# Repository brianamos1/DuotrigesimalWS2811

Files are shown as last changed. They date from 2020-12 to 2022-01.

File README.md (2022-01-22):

# DuotrigesimalWS2811
A board for driving 32 strings of pixels from a Teensy 4.1. Similar to the OctoWS2811, but with 32 outputs. 

This board interfaces with a Teensy 4.1, and is designed to use the OctoWS2811 library to drive up to 32 strings of LEDS. 

Version 0.2 is designed to use the Amphenol RJHSE508004-ND, which is a four port RJ45 jack.  Version 0.2a uses the Adam Tech MTJG-4-88GX1-FSB, which is a less expensive and more readily available alternative.

The 2x3 pin that connects the board to the Teensy 4.1's ethernet pins is available on digikey and mouser, however is easier to source from PJRC when purchasing the Teensy 4.1.  If you want the teensy to be removable, PJRC is the recommended source for that connector.  If you're going to solder the T4.1 to this board, then it doesn't matter the source for the pins.  ‎

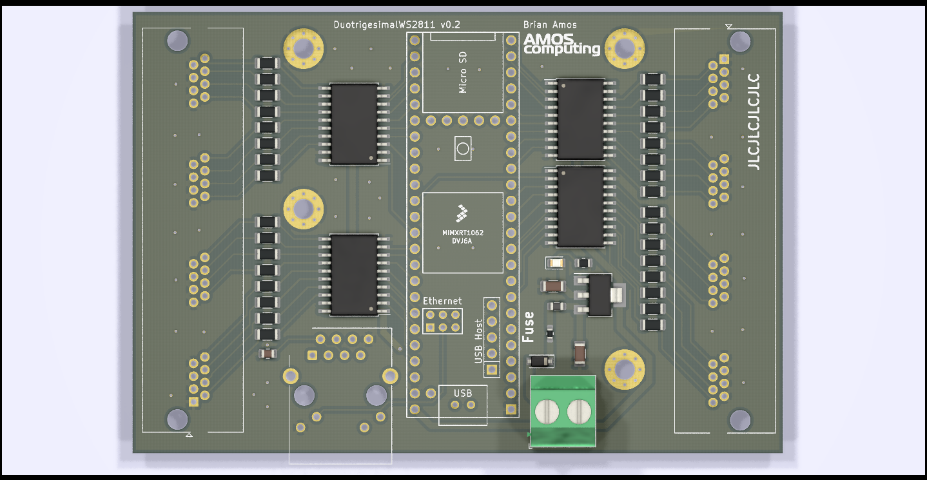
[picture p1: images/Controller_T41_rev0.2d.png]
Board Render


Boards are available for purchase at https://www.tindie.com/products/25767/

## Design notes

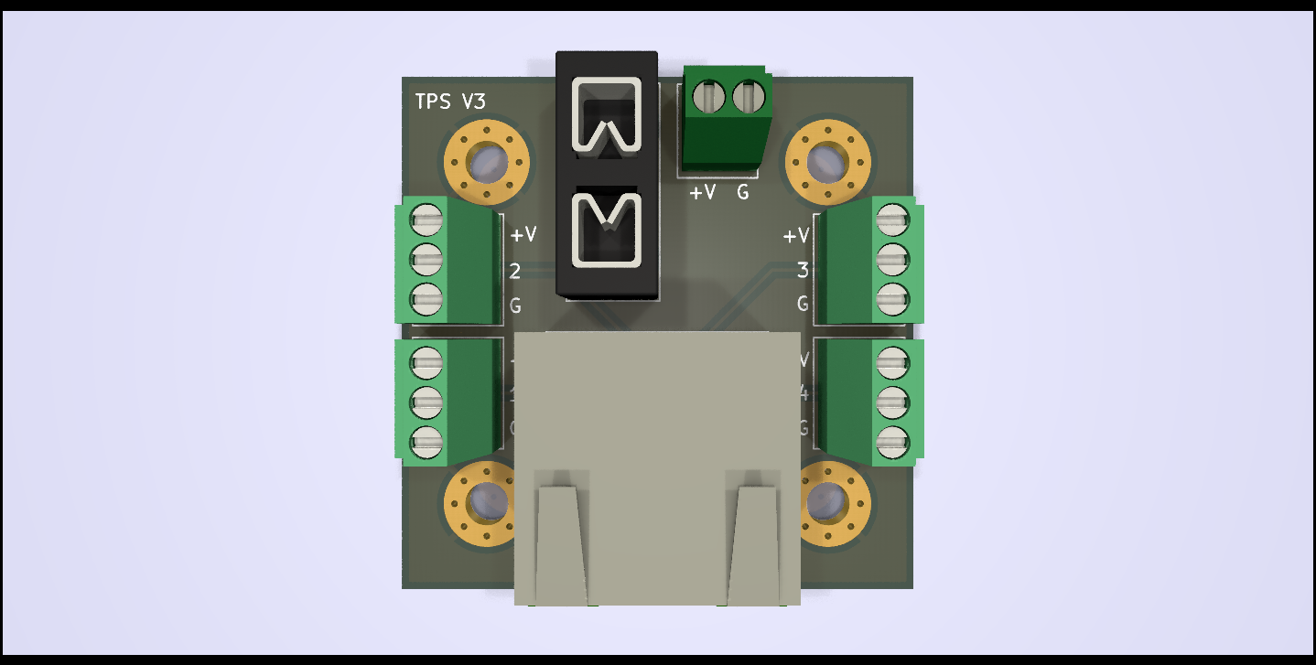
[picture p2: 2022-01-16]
Splitter-0.3/images/splitter0.3-filled-front.png

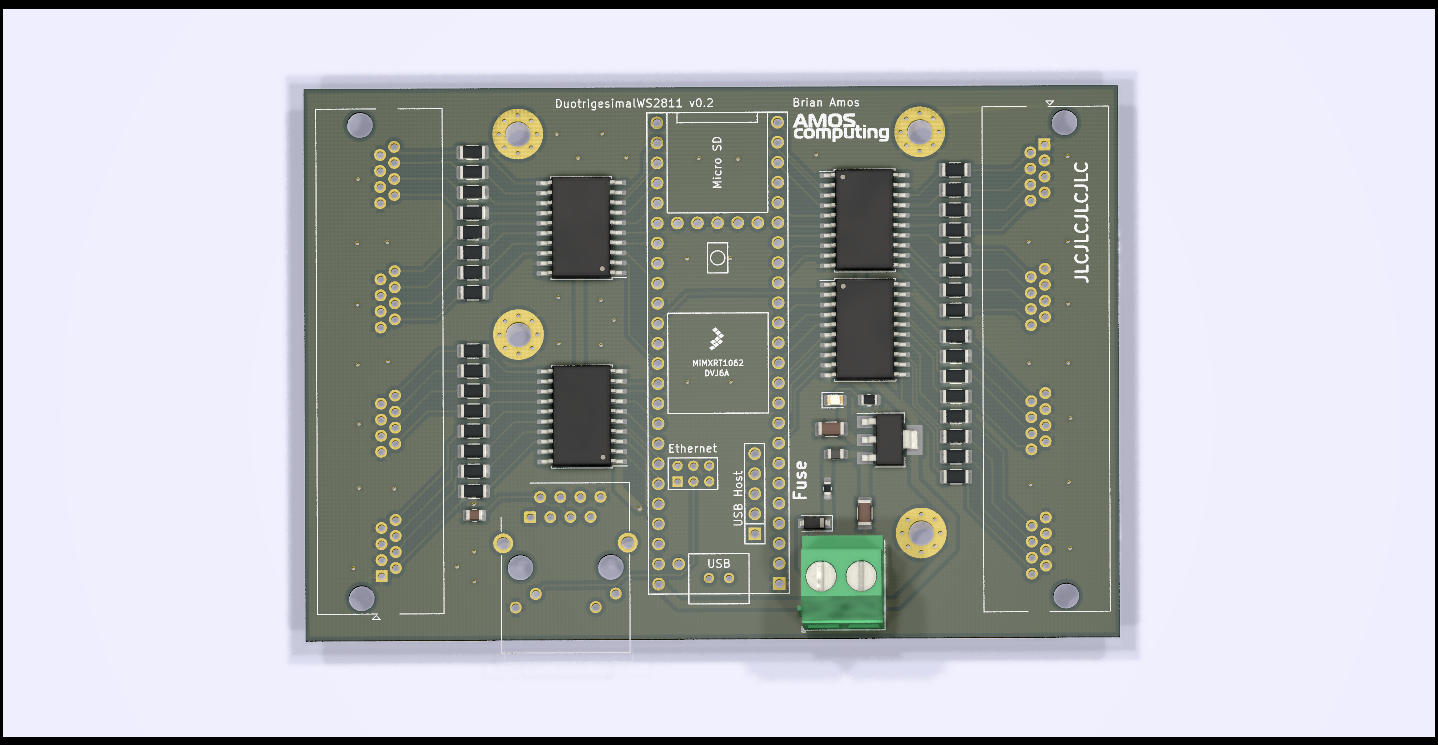
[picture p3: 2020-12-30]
images/Controller_T41_rev0.2c.png

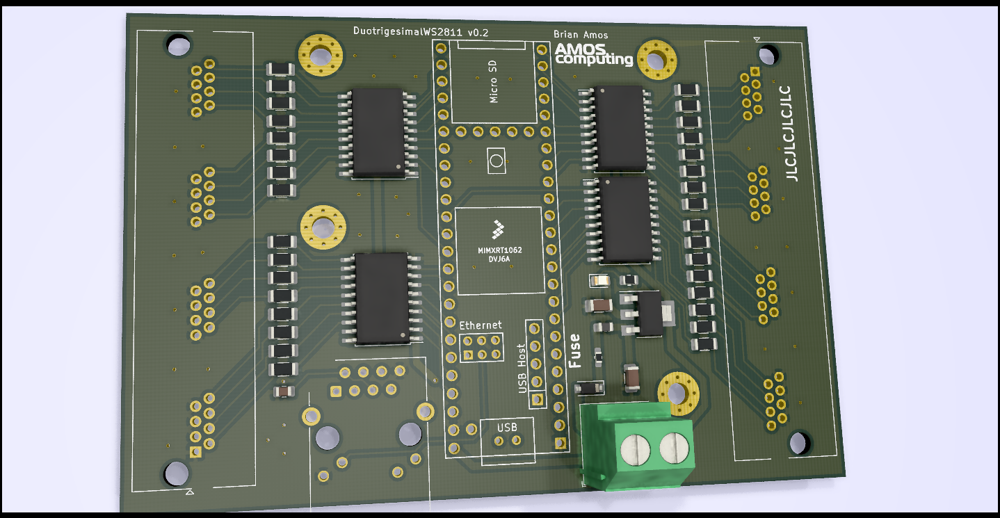
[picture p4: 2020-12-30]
images/Controller_T41_rev0.2b.png

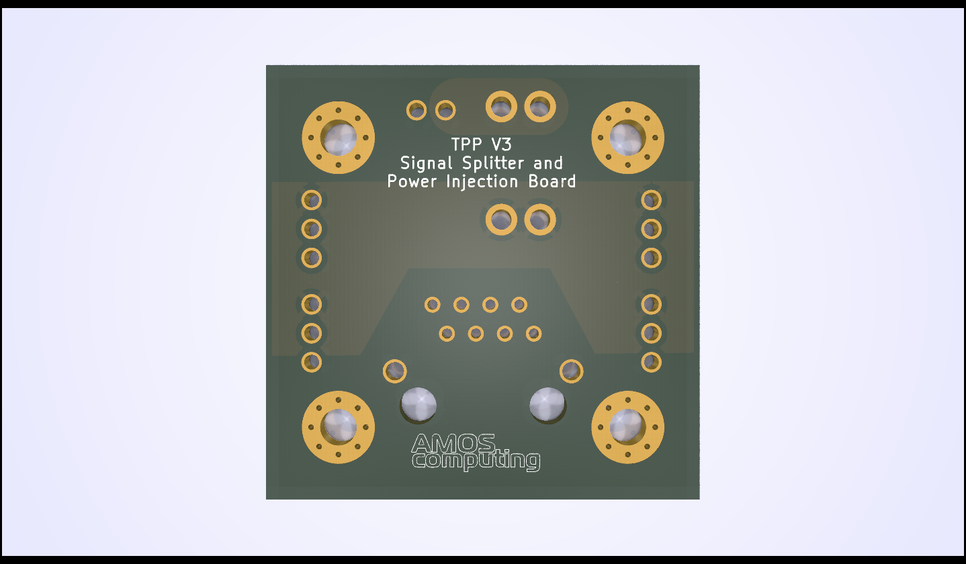
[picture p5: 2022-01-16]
Splitter-0.3/images/splitter0.3-bare-back.png

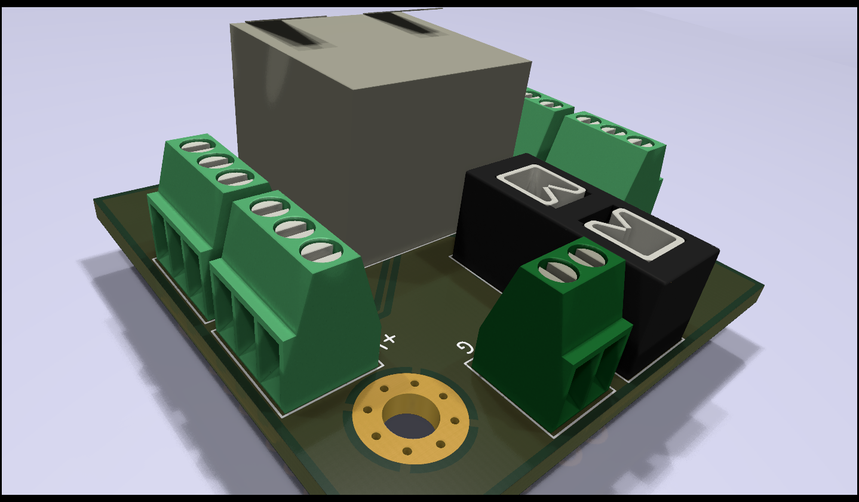
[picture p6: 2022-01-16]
Splitter-0.3/images/splitter0.2-full-side.png

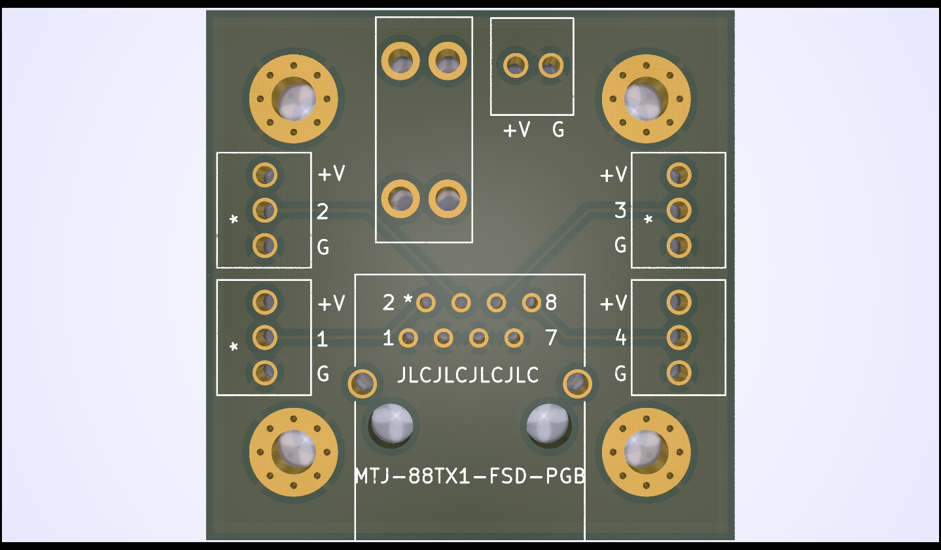
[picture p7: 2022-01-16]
Splitter-0.3/images/splitter0.2-bare.png

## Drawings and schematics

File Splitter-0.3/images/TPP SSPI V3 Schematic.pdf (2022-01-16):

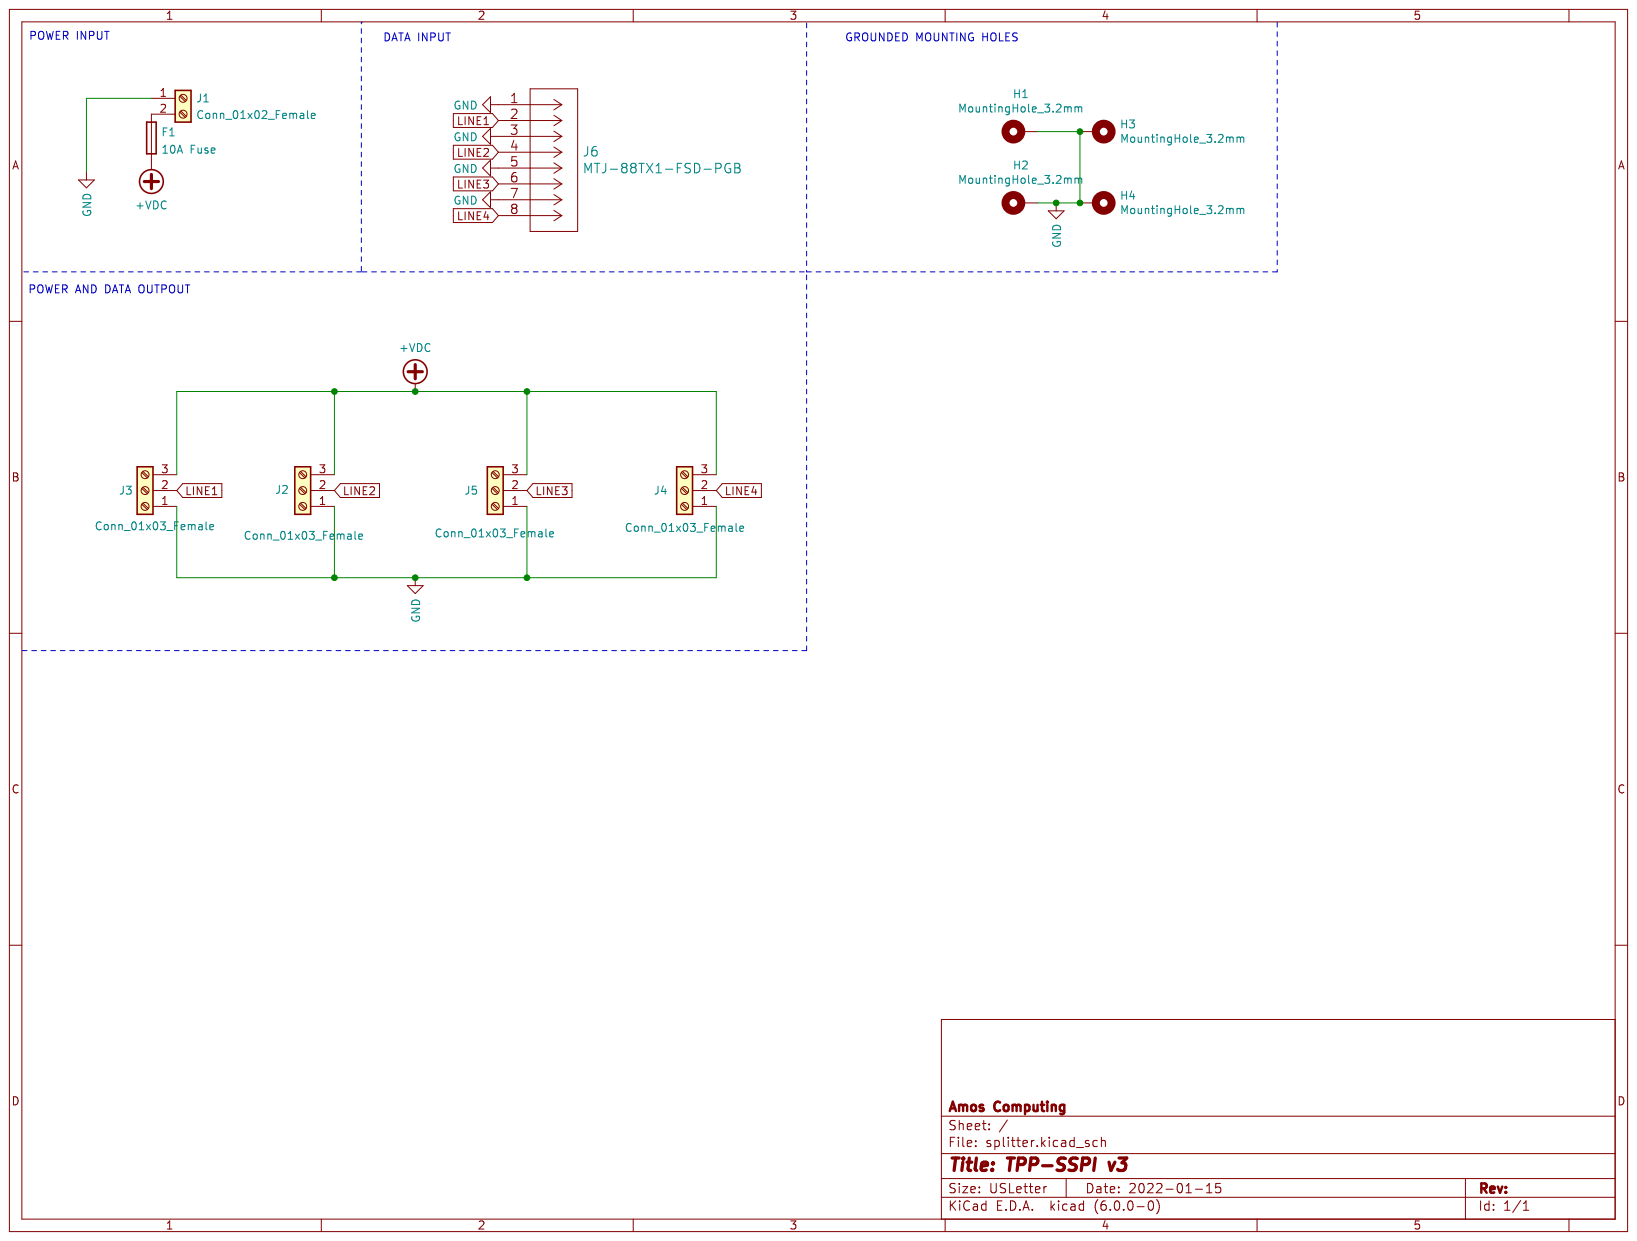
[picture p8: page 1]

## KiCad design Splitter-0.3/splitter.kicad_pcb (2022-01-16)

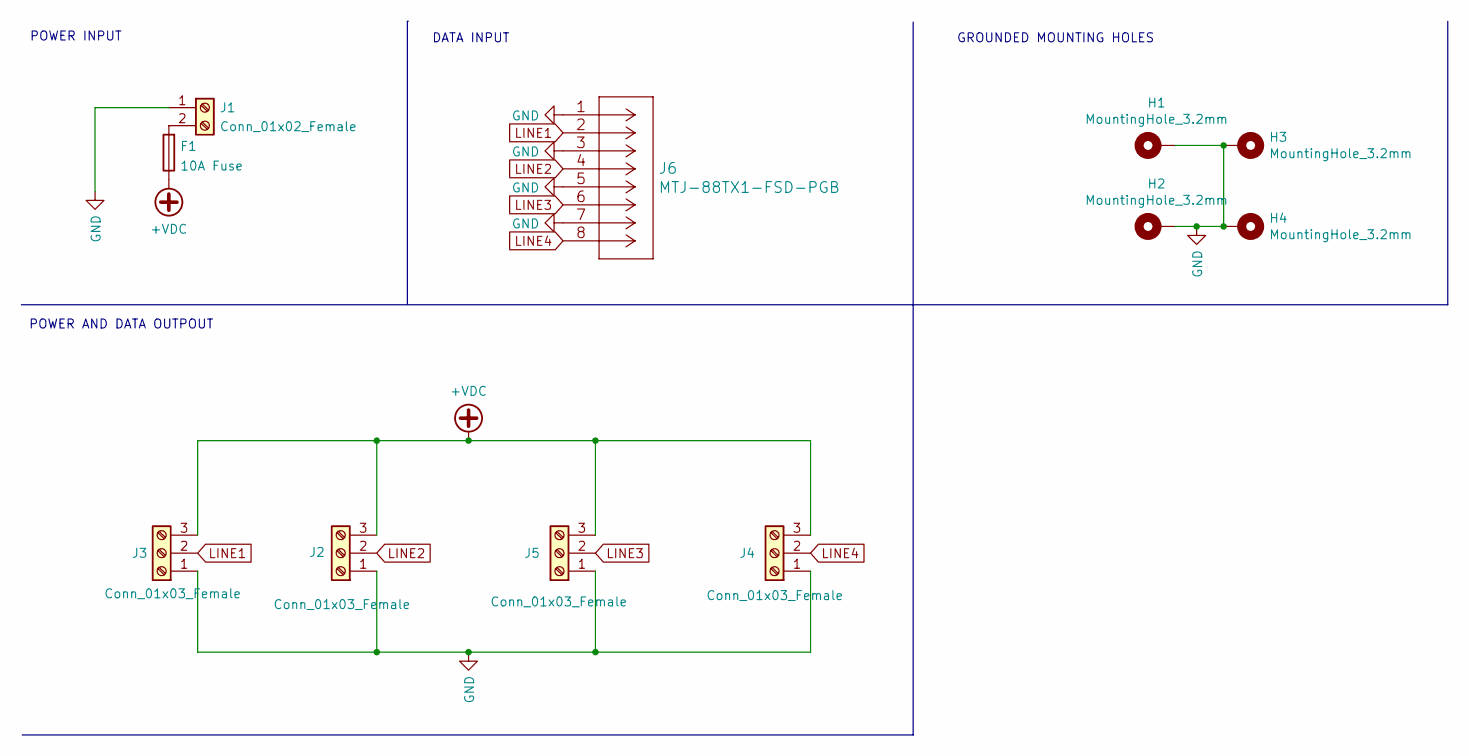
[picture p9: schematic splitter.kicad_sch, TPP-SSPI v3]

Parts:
F1: 10A Fuse; Fuseholder_Blade_Mini_Keystone_3568
H1, H2, H3, H4: MountingHole_3.2mm; MountingHole_3.2mm_M3_Pad_Via
J1: Conn_01x02_Female; TerminalBlock_OST_02A150-2_P2.54mm
J2, J3, J4, J5: Conn_01x03_Female; TerminalBlock_OST_03A150-3_P2.54mm
J6: MTJ-88TX1-FSD-PGB; RJ45_AdamTech_MTJ-88TX1-FSD-PGB

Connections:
+VDC: F1.1, J2.3, J3.3, J4.3, J5.3
GND: H1.1, H2.1, H3.1, H4.1, J1.1, J2.1, J3.1, J4.1, J5.1, J6.1, J6.3, J6.5, J6.7, J6.12, J6.13
LINE1: J3.2, J6.2
LINE2: J2.2, J6.4
LINE3: J5.2, J6.6
LINE4: J4.2, J6.8
unnamed: F1.2, J1.2

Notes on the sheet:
DATA INPUT
POWER INPUT
GROUNDED MOUNTING HOLES
POWER AND DATA OUTPOUT

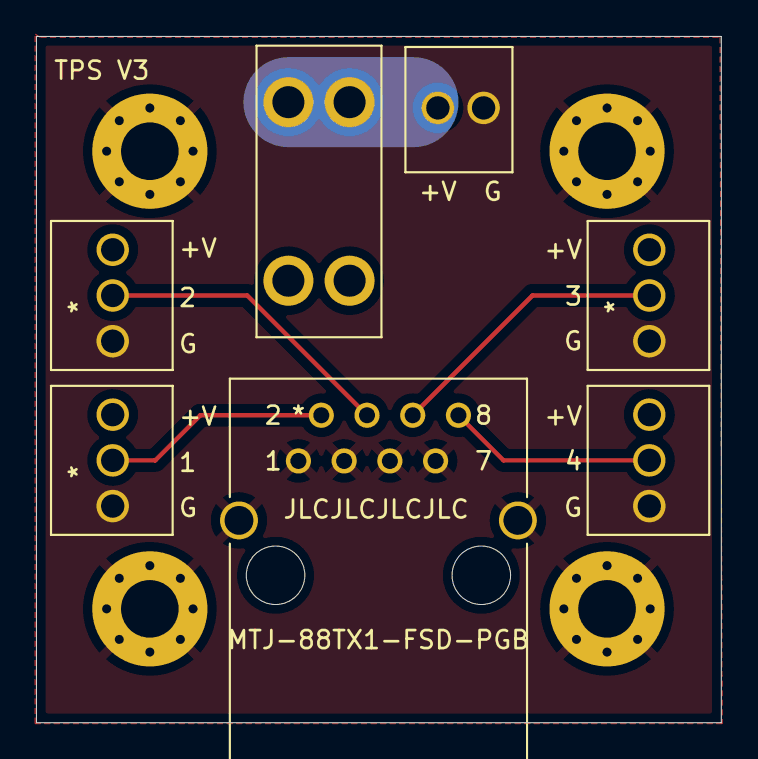
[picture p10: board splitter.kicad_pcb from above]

Board: 2 copper layers, 38.0 x 38.1 mm, 11 parts (0 on the bottom side), 7 nets.

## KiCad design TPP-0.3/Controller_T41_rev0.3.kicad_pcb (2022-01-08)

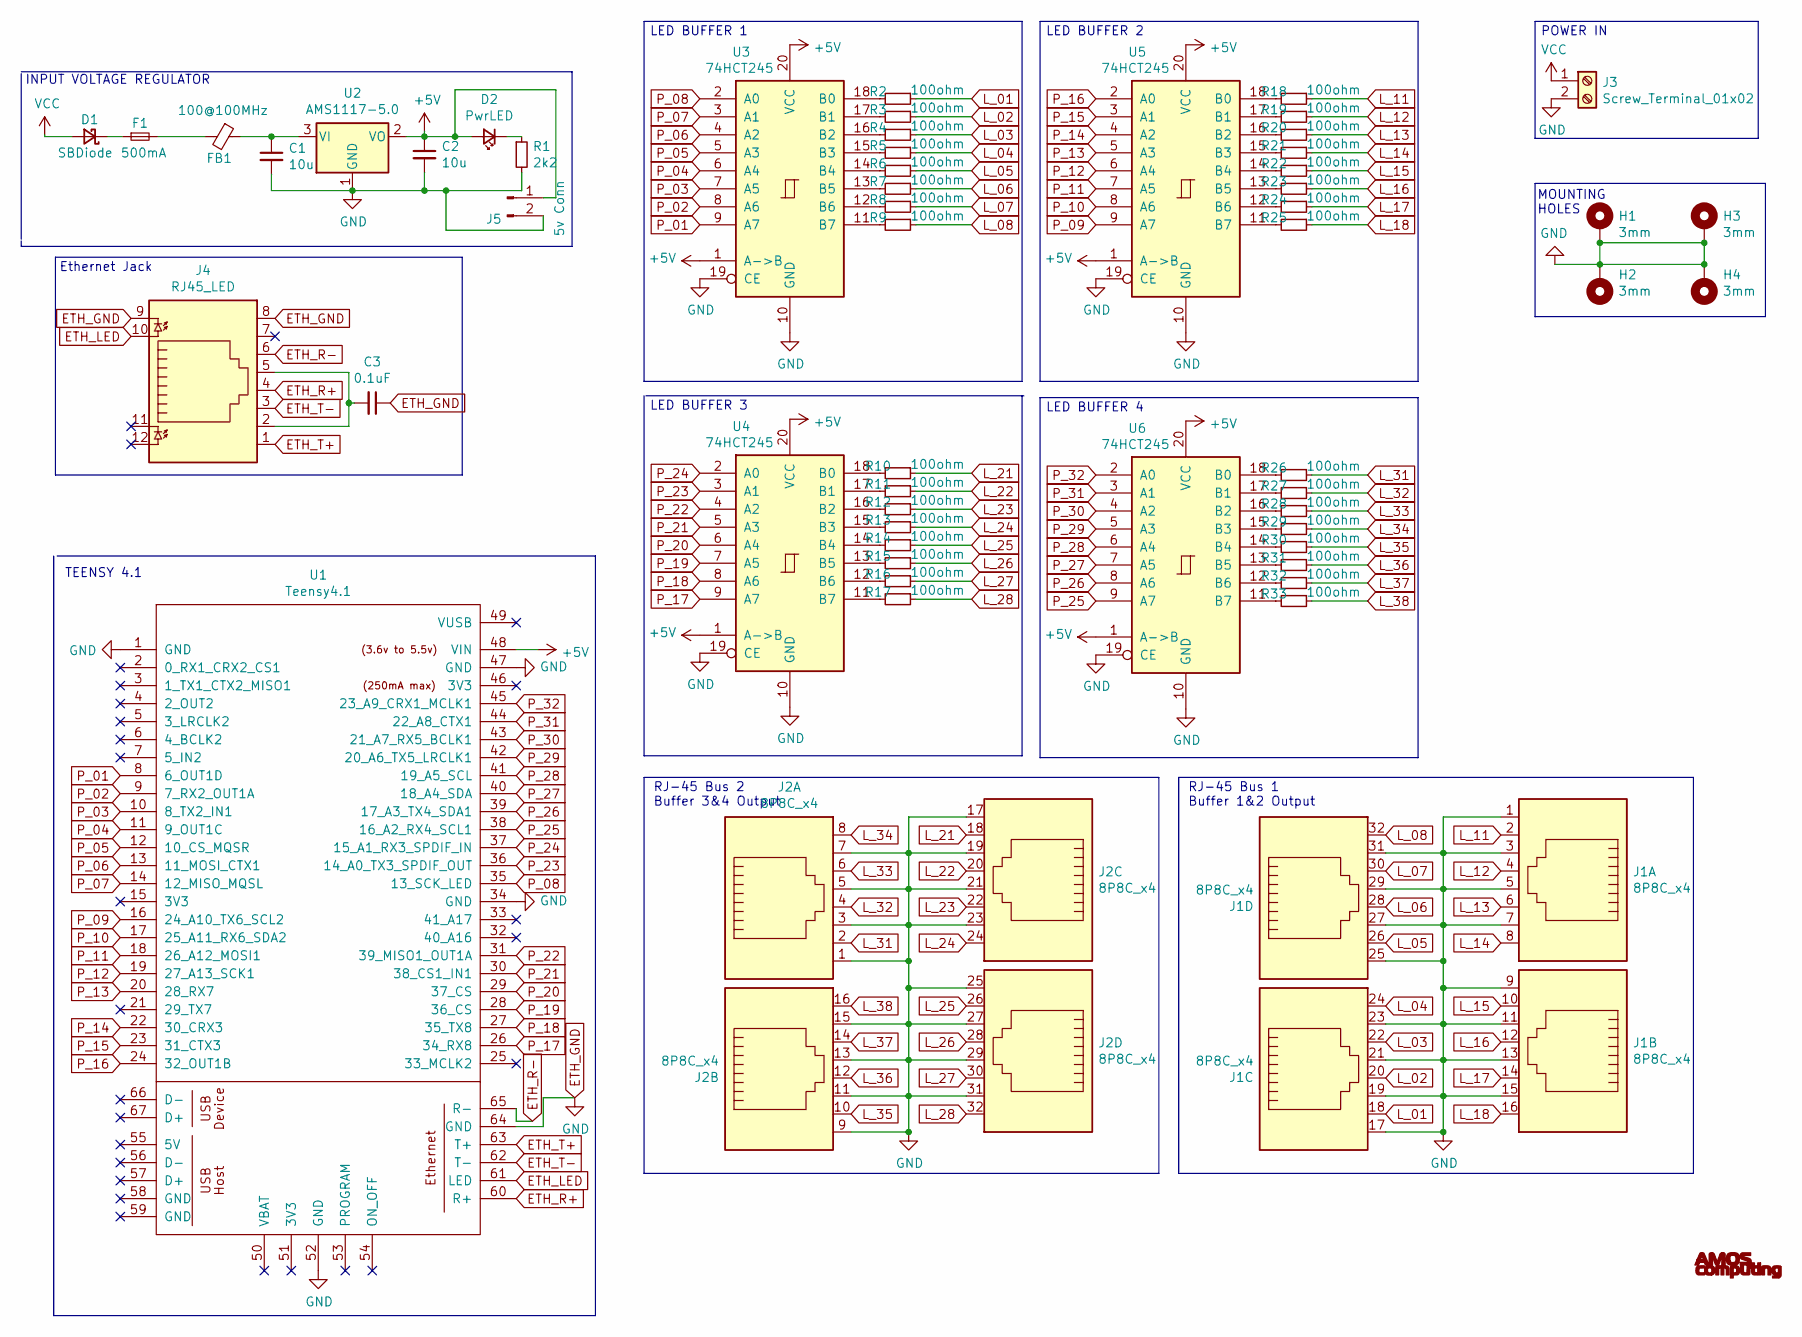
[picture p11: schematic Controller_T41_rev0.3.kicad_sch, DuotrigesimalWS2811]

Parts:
C1, C2: 10u; C_1206_3216Metric; LCSC C13585
C3: 0.1uF; C_0805_2012Metric; LCSC C49678
D1: SBDiode; D_SOD-123; Part Number B5819W; LCSC C8598
D2: PwrLED; LED_0603_1608Metric; LCSC C2286
F1: 500mA; Fuse_1206_3216Metric_Pad1.42x1.75mm_HandSolder
FB1: 100@100MHz; L_0805_2012Metric; Part Number GZ2012D101TF Ferrite Bead; LCSC C1015
H1, H2, H3, H4: 3mm; MountingHole_3.2mm_M3_Pad_Via
J1, J2: 8P8C_x4; RJ45_Amphenol_RJHSE508004-ND‎
J3: Screw_Terminal_01x02; TerminalBlock_Phoenix_MKDS-3-2-5.08_1x02_P5.08mm_Horizontal
J4: RJ45_LED; RJ45_Cetus_J1B1211CCD_Horizontal
J5: 5v Conn; PinHeader_1x02_P2.54mm_Vertical
R1: 2k2; R_0805_2012Metric; LCSC C17520
R2, R3, R4, R5, R6, R7, R8, R9, R10, R11, R12, R13, R14, R15, R16, R17, R18, R19, R20, R21, R22, R23, R24, R25, R26, R27, R28, R29, R30, R31, R32, R33: 100ohm; R_01005_0402Metric; LCSC C25076
U1: Teensy4.1; Teensy41
U2: AMS1117-5.0; SOT-223-3_TabPin2; LCSC C6187
U3, U4, U5, U6: 74HCT245; SOIC-20W_7.5x12.8mm_P1.27mm; LCSC C110789

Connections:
+5V: C2.1, D2.2 (A), J5.1, U1.48 (VIN), U2.2 (VO), U3.1 (A->B), U3.20 (VCC), U4.1 (A->B), U4.20 (VCC), U5.1 (A->B), U5.20 (VCC), U6.1 (A->B), U6.20 (VCC)
ETH_GND: C1.2, C2.2, C3.1, H1.1, H2.1, H3.1, H4.1, J1.1, J1.3, J1.5, J1.7, J1.9, J1.11, J1.13, J1.15, J1.17, J1.19, J1.21, J1.23, J1.25, J1.27, J1.29, J1.31, J2.1, J2.3, J2.5, J2.7, J2.9, J2.11, J2.13, J2.15, J2.17, J2.19, J2.21, J2.23, J2.25, J2.27, J2.29, J2.31, J3.2, J4.8, J4.9, J5.2, R1.2, U1.1 (GND), U1.34 (GND), U1.47 (GND), U1.52 (GND), U1.64 (GND), U2.1 (GND), U3.10 (GND), U3.19 (CE), U4.10 (GND), U4.19 (CE), U5.10 (GND), U5.19 (CE), U6.10 (GND), U6.19 (CE)
ETH_LED: J4.10, U1.61 (LED)
ETH_R+: J4.4, U1.60 (R+)
ETH_R-: J4.6, U1.65 (R-)
ETH_T+: J4.1, U1.63 (T+)
ETH_T-: J4.3, U1.62 (T-)
L_01: J1.18, R2.1
L_02: J1.20, R3.1
L_03: J1.22, R4.1
L_04: J1.24, R5.1
L_05: J1.26, R6.1
L_06: J1.28, R7.1
L_07: J1.30, R8.1
L_08: J1.32, R9.1
L_11: J1.2, R18.1
L_12: J1.4, R19.1
L_13: J1.6, R20.1
L_14: J1.8, R21.1
L_15: J1.10, R22.1
L_16: J1.12, R23.1
L_17: J1.14, R24.1
L_18: J1.16, R25.1
L_21: J2.18, R10.1
L_22: J2.20, R11.1
L_23: J2.22, R12.1
L_24: J2.24, R13.1
L_25: J2.26, R14.1
L_26: J2.28, R15.1
L_27: J2.30, R16.1
L_28: J2.32, R17.1
L_31: J2.2, R26.1
L_32: J2.4, R27.1
L_33: J2.6, R28.1
L_34: J2.8, R29.1
L_35: J2.10, R30.1
L_36: J2.12, R31.1
L_37: J2.14, R32.1
L_38: J2.16, R33.1
unnamed: C1.1, FB1.1, U2.3 (VI)
unnamed: C3.2, J4.2, J4.5
unnamed: D1.1 (K), F1.1
unnamed: D2.1 (K), R1.1
unnamed: F1.2, FB1.2
unnamed: R2.2, U3.18 (B0)
unnamed: R3.2, U3.17 (B1)
unnamed: R4.2, U3.16 (B2)
unnamed: R5.2, U3.15 (B3)
unnamed: R6.2, U3.14 (B4)
unnamed: R7.2, U3.13 (B5)
unnamed: R8.2, U3.12 (B6)
unnamed: R9.2, U3.11 (B7)
unnamed: R10.2, U4.18 (B0)
unnamed: R11.2, U4.17 (B1)
unnamed: R12.2, U4.16 (B2)
unnamed: R13.2, U4.15 (B3)
unnamed: R14.2, U4.14 (B4)
unnamed: R15.2, U4.13 (B5)
unnamed: R16.2, U4.12 (B6)
unnamed: R17.2, U4.11 (B7)
unnamed: R18.2, U5.18 (B0)
unnamed: R19.2, U5.17 (B1)
unnamed: R20.2, U5.16 (B2)
unnamed: R21.2, U5.15 (B3)
unnamed: R22.2, U5.14 (B4)
unnamed: R23.2, U5.13 (B5)
unnamed: R24.2, U5.12 (B6)
unnamed: R25.2, U5.11 (B7)
unnamed: R26.2, U6.18 (B0)
unnamed: R27.2, U6.17 (B1)
unnamed: R28.2, U6.16 (B2)
unnamed: R29.2, U6.15 (B3)
unnamed: R30.2, U6.14 (B4)
unnamed: R31.2, U6.13 (B5)
unnamed: R32.2, U6.12 (B6)
unnamed: R33.2, U6.11 (B7)
P_01: U1.8 (6_OUT1D), U3.9 (A7)
P_02: U1.9 (7_RX2_OUT1A), U3.8 (A6)
P_03: U1.10 (8_TX2_IN1), U3.7 (A5)
P_04: U1.11 (9_OUT1C), U3.6 (A4)
P_05: U1.12 (10_CS_MQSR), U3.5 (A3)
P_06: U1.13 (11_MOSI_CTX1), U3.4 (A2)
P_07: U1.14 (12_MISO_MQSL), U3.3 (A1)
P_08: U1.35 (13_SCK_LED), U3.2 (A0)
P_09: U1.16 (24_A10_TX6_SCL2), U5.9 (A7)
P_10: U1.17 (25_A11_RX6_SDA2), U5.8 (A6)
P_11: U1.18 (26_A12_MOSI1), U5.7 (A5)
P_12: U1.19 (27_A13_SCK1), U5.6 (A4)
P_13: U1.20 (28_RX7), U5.5 (A3)
P_14: U1.22 (30_CRX3), U5.4 (A2)
P_15: U1.23 (31_CTX3), U5.3 (A1)
P_16: U1.24 (32_OUT1B), U5.2 (A0)
P_17: U1.26 (34_RX8), U4.9 (A7)
P_18: U1.27 (35_TX8), U4.8 (A6)
P_19: U1.28 (36_CS), U4.7 (A5)
P_20: U1.29 (37_CS), U4.6 (A4)
P_21: U1.30 (38_CS1_IN1), U4.5 (A3)
P_22: U1.31 (39_MISO1_OUT1A), U4.4 (A2)
P_23: U1.36 (14_A0_TX3_SPDIF_OUT), U4.3 (A1)
P_24: U1.37 (15_A1_RX3_SPDIF_IN), U4.2 (A0)
P_25: U1.38 (16_A2_RX4_SCL1), U6.9 (A7)
P_26: U1.39 (17_A3_TX4_SDA1), U6.8 (A6)
P_27: U1.40 (18_A4_SDA), U6.7 (A5)
P_28: U1.41 (19_A5_SCL), U6.6 (A4)
P_29: U1.42 (20_A6_TX5_LRCLK1), U6.5 (A3)
P_30: U1.43 (21_A7_RX5_BCLK1), U6.4 (A2)
P_31: U1.44 (22_A8_CTX1), U6.3 (A1)
P_32: U1.45 (23_A9_CRX1_MCLK1), U6.2 (A0)
VCC: D1.2 (A), J3.1

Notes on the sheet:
INPUT VOLTAGE REGULATOR
MOUNTING HOLES
LED BUFFER 1
RJ-45 Bus 2 Buffer 3&4 Output
Ethernet Jack
LED BUFFER 4
POWER IN
LED BUFFER 2
RJ-45 Bus 1 Buffer 1&2 Output
LED BUFFER 3
TEENSY 4.1

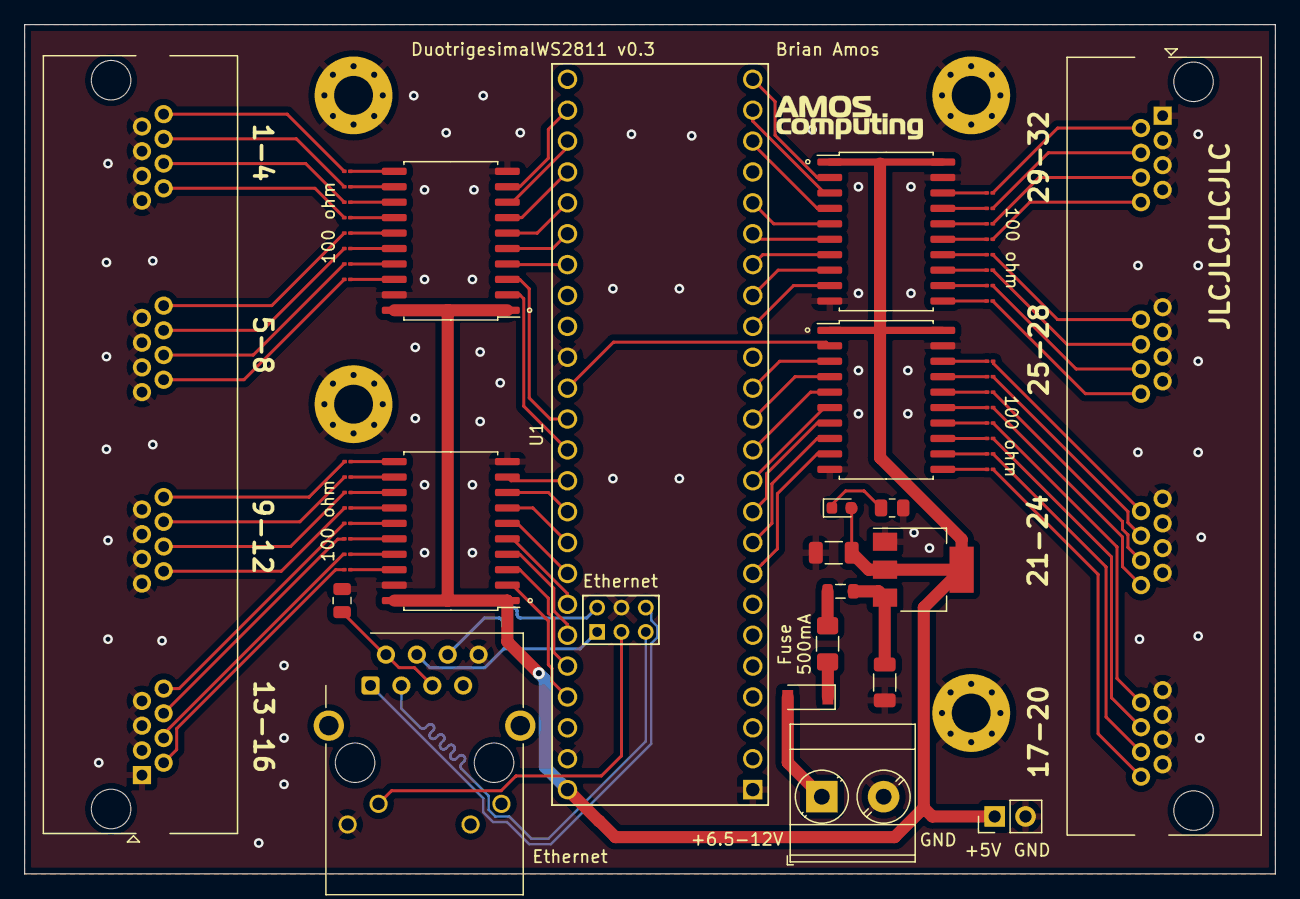
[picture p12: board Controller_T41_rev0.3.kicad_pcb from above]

Board: 2 copper layers, 102.9 x 69.9 mm, 55 parts (0 on the bottom side), 109 nets.

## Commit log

2020-11-02 Initial Project
    Upload initial project
    [Controller_T41_rev0.1.kicad_pcb, Controller_T41_rev0.1.sch, layout2.kicad_pcb]
2020-11-02 Changes to be committed: modified: Controller_T41_rev0.1.kicad_pcb modified: Controller_T41_rev0.1.kicad_pcb-bak
    [Controller_T41_rev0.1.kicad_pcb]
2020-11-03 modified: Controller_T41_rev0.1.kicad_pcb modified: Controller_T41_rev0.1.kicad_pcb-bak modified: Controller_T41_rev0.1.net modified: Controller_T41_rev0.1.sch-bak modified: fp-info-cache
    [Controller_T41_rev0.1.kicad_pcb]
2020-11-06 updated board layout, converted rj-45 ports to dual rj-45 ports Converted design to kicad 5.
    [Controller_T41_rev0.1.kicad_pcb, Controller_T41_rev0.1.sch, layout2.kicad_pcb]
2020-11-07 modified: Controller_T41_rev0.1.kicad_pcb Added board outline.
    [Controller_T41_rev0.1.kicad_pcb]
2020-11-11 Switching to SMT components where possible
    [Controller_T41_rev0.1.kicad_pcb, Controller_T41_rev0.1.sch]
2020-11-16 Changes: bringing current version to 0.2, redrew schematic to make it more clear, using 2x4 port rj45 for output, new board layout with smt parts deleted: Controller_T41_rev0.1.kicad_pcb deleted: Con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
    [Controller_T41_rev0.1.kicad_pcb, Controller_T41_rev0.1.sch, Controller_T41_rev0.2.kicad_pcb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]
2020-11-16 Cleaning up files
    [layout2.kicad_pcb]
2020-11-16 Minor changes to silkscreen
2020-11-18 Changed buffer to 74HCT245 from 74HC245
    [Controller_T41_rev0.2.sch]
2020-11-21 Updated schematic layout and parts. Minor updates to footprint.
    [Controller_T41_rev0.2.kicad_pcb, Controller_T41_rev0.2.sch]
2020-11-21 new file: Controller_T41_rev0.2.pretty/logo.kicad_mod new file: Controller_T41_rev0.2.pretty/logo.lib
2020-12-30 new file: AC_Logo.kicad_mod
2020-12-30 added kicad generated board images
2020-12-30 Updated some parts on LCSC and some smt components
    [Controller_T41_rev0.2.kicad_pcb, Controller_T41_rev0.2.sch]
2021-01-01 Upgraded to Kicad 5.1.9
    [Controller_T41_rev0.2.kicad_pcb, Controller_T41_rev0.2.sch]
2021-01-01 Added headers to 3d view
    [Controller_T41_rev0.2.kicad_pcb]
2021-01-03 Minor Part Updates
    [Controller_T41_rev0.2.kicad_pcb]
2021-01-03 Initilized Version 0.3 with smaller components and better labeling.
    [Controller_T41_rev0.3.kicad_pcb, Controller_T41_rev0.3.sch]
2021-01-03 Smaller resistors, larger fuse, additional labeling on silkscreen
    [Controller_T41_rev0.3.kicad_pcb, Controller_T41_rev0.3.sch]
2021-01-04 Minor Placement Updates
    [Controller_T41_rev0.3.kicad_pcb, Controller_T41_rev0.3.sch]
2022-01-07 Adding a revision to 0.2 labeled 0.2a in order to use more available parts.
    [Controller_T41_rev0.2a-B_Cu.gbl, Controller_T41_rev0.2a-B_Mask.gbs, Controller_T41_rev0.2a-B_Paste.gbp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]
2022-01-08 added folder organization for different versions
    [Controller_T41_rev0.2.kicad_pcb, Controller_T41_rev0.2.sch, Controller_T41_rev0.2a.kicad_pcb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]
2022-01-08 continue updating file locations
    [Controller_T41_rev0.2.kicad_pcb, Controller_T41_rev0.2.sch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]
2022-01-08 Updated rev0.3 to KiCad 6
    [Controller_T41_rev0.3.kicad_pcb, Controller_T41_rev0.3.kicad_sch]
2022-01-08 added Splitter/Power Injector rev0.1
    [splitter.kicad_pcb, splitter.kicad_sch]
2022-01-16 Added version 3 of the splitter to this project
    [splitter.kicad_pcb, splitter.kicad_sch]

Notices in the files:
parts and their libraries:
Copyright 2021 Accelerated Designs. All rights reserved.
